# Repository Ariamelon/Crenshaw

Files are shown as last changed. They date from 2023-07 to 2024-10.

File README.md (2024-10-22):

# Crenshaw
1.5" SSD1351 RGB OLED [VIK](https://github.com/sadekbaroudi/vik) module.

## Disclaimer
This board is licensed under CERN-OHL-S-2.0.

## VIK module certification card

| Category | Classification | Response |
| --- | --- | --- |
| FPC connector | Required | :heavy_check_mark: |
| Breakout pins | Recommended | :x: |
| Uses: SPI | Optional | :heavy_check_mark: |
| SPI used for SPI only | Strongly recommended | :heavy_check_mark: |
| Uses: I2C | Optional | :x: |
| I2C used for I2C only | Strongly Recommended | N/A |
| I2C pull ups | Required | N/A |
| Uses: RGB | Optional | :x: |
| Uses: Extra GPIO 1 | Optional | :heavy_check_mark: |
| Uses: Extra GPIO 2 | Optional | :heavy_check_mark: |
| Standard PCB Size/Mount | Strongly Recommended | :x: |

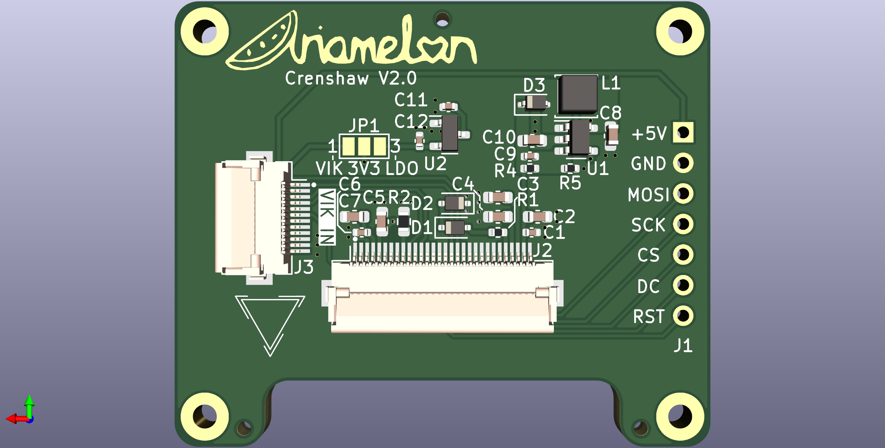
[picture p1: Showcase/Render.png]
Render


## Changelog
 * 22/10/2024: License updated to CERN-OHL-S-2.0.
* 04/08/2023: Changed VIK and OLED FFC to FH12. Stitched ground planes together. Fixed VIK footprint. Moved production files to easier to access location.
* 28/07/2023: Added pin labels. Added VIK size row to certification card.
* 27/07/2023: Added voltage regulator, SSD1351 supporting circuitry and [VIK](https://github.com/sadekbaroudi/vik) connector. Added license. Added metadata to schematic and board files. Added VIK module certification card.
* 26/07/2023: Updated to V2.0.
* 11/11/2020: Updated to V1.2. Slightly increased size. Moved ribbon cable connector away from center of board as it was causing issues where it was. Spread components apart to allow for easier soldering.
* 30/09/2020: Updated to V1.1. Fixed orientation of I2C headers, increased silkscreen text size, moved ribbon cable connector further towards center of board.
* 29/09/2020: D1 SOD323 switched to SOD123.
* 27/09/2020: Initial commit.

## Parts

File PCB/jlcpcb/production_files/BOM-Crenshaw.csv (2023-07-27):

Comment | Designator | Footprint | LCSC
22p | C9 | C_0402_1005Metric | C1555
1u | C3,C4,C5,C7 | C_0603_1608Metric | C15849
1N5819WS | D3 | D_SOD-323 | C191023
4u7 | C10,C8 | C_0603_1608Metric | C19666
10u | L1 | L_Sunlord_SWPA3012S | C206385
1N4148 | D1,D2 | D_SOD-323 | C2128
560k | R2 | R_0603_1608Metric | C23203
51 | R1 | R_0402_1005Metric | C25125
100k | R5 | R_0402_1005Metric | C25741
1M | R4 | R_0402_1005Metric | C26083
100n | C1,C6 | C_0402_1005Metric | C307331
SSD1351 | J2 | HRS_FH34SRJ-30S-0.5SH(50) | C324727
VIK Module | J3 | vik-module-connector-horizontal | C424659
1u | C11,C12 | C_0402_1005Metric | C52923
XC6206P332MR | U2 | SOT-23 | C5446
TPS61040DBV | U1 | SOT-23-5 | C7722
10u | C2 | C_0603_1608Metric | C96446
OLED_Breakout | J1 | OLED_1.5_SSD1351_128x128

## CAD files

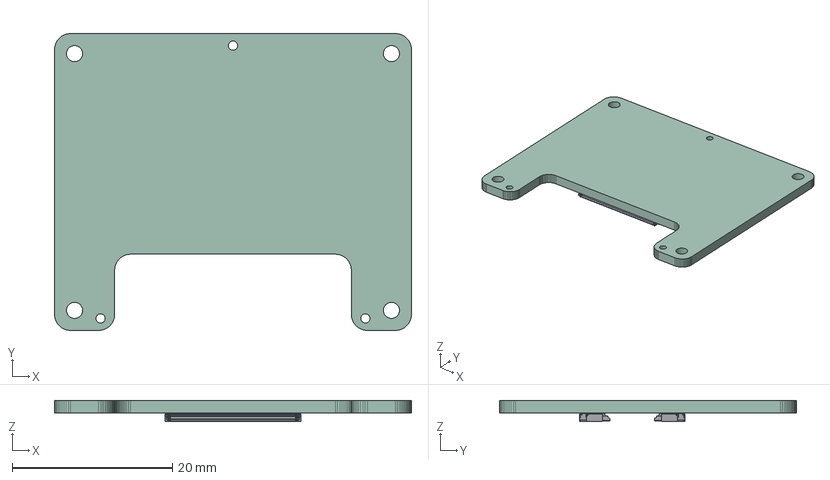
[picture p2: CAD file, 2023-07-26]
Showcase/Crenshaw.step
44.5 x 37.0 x 2.65 mm
Crenshaw PCB

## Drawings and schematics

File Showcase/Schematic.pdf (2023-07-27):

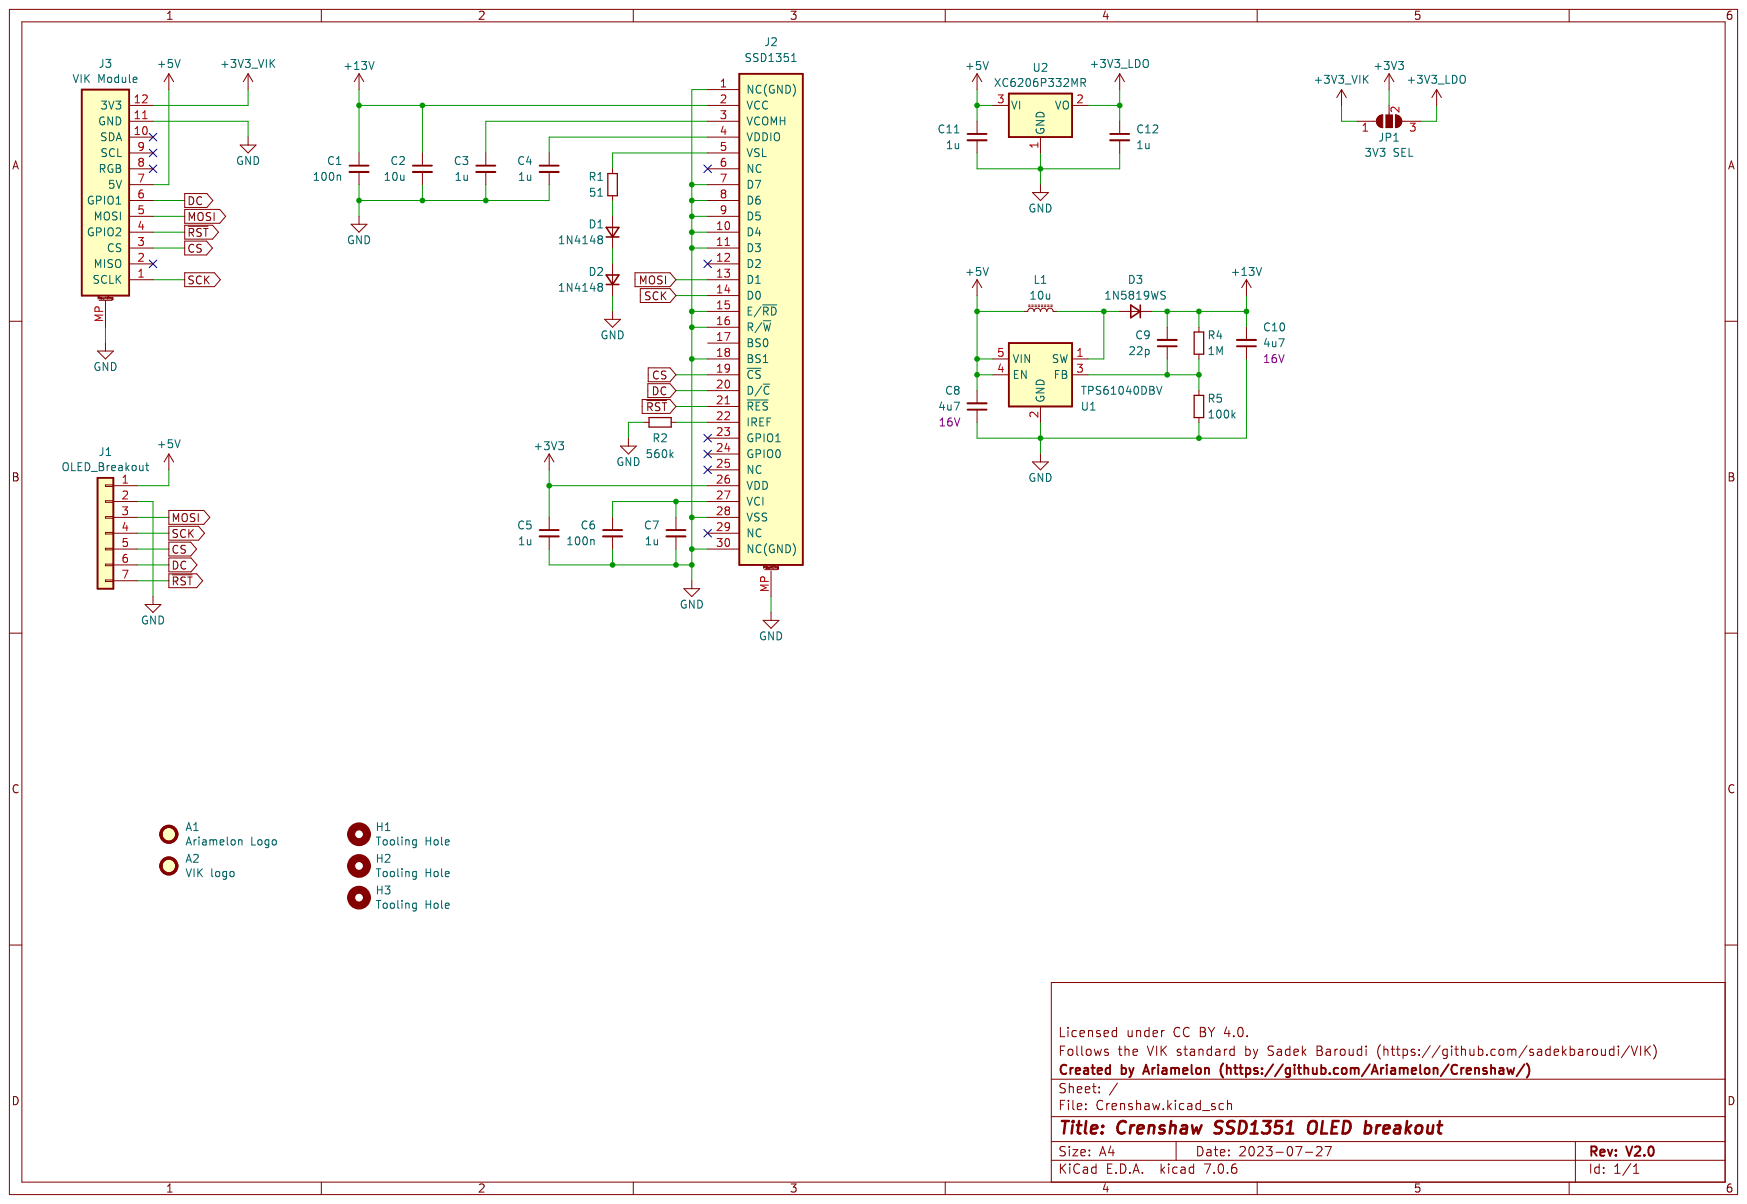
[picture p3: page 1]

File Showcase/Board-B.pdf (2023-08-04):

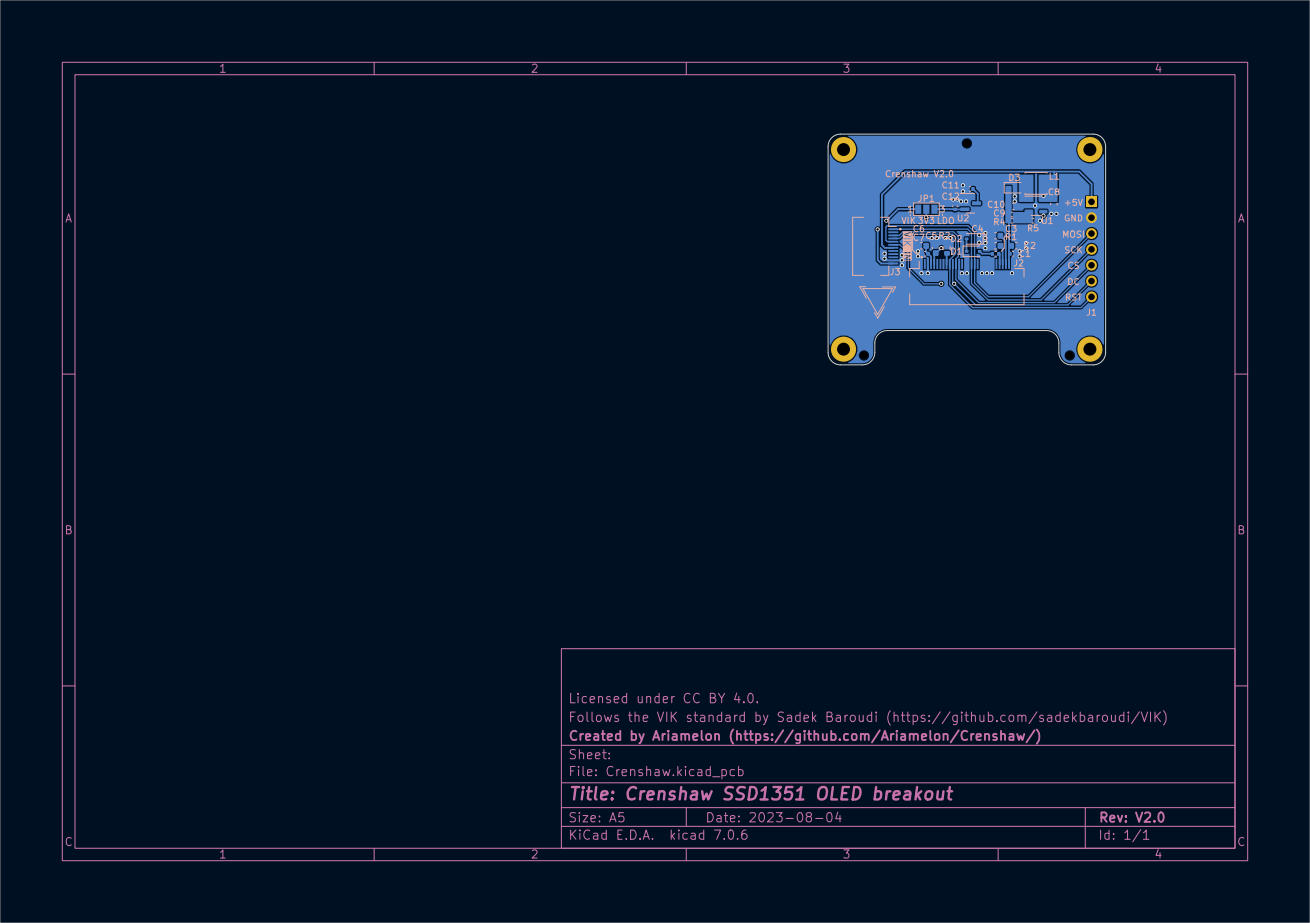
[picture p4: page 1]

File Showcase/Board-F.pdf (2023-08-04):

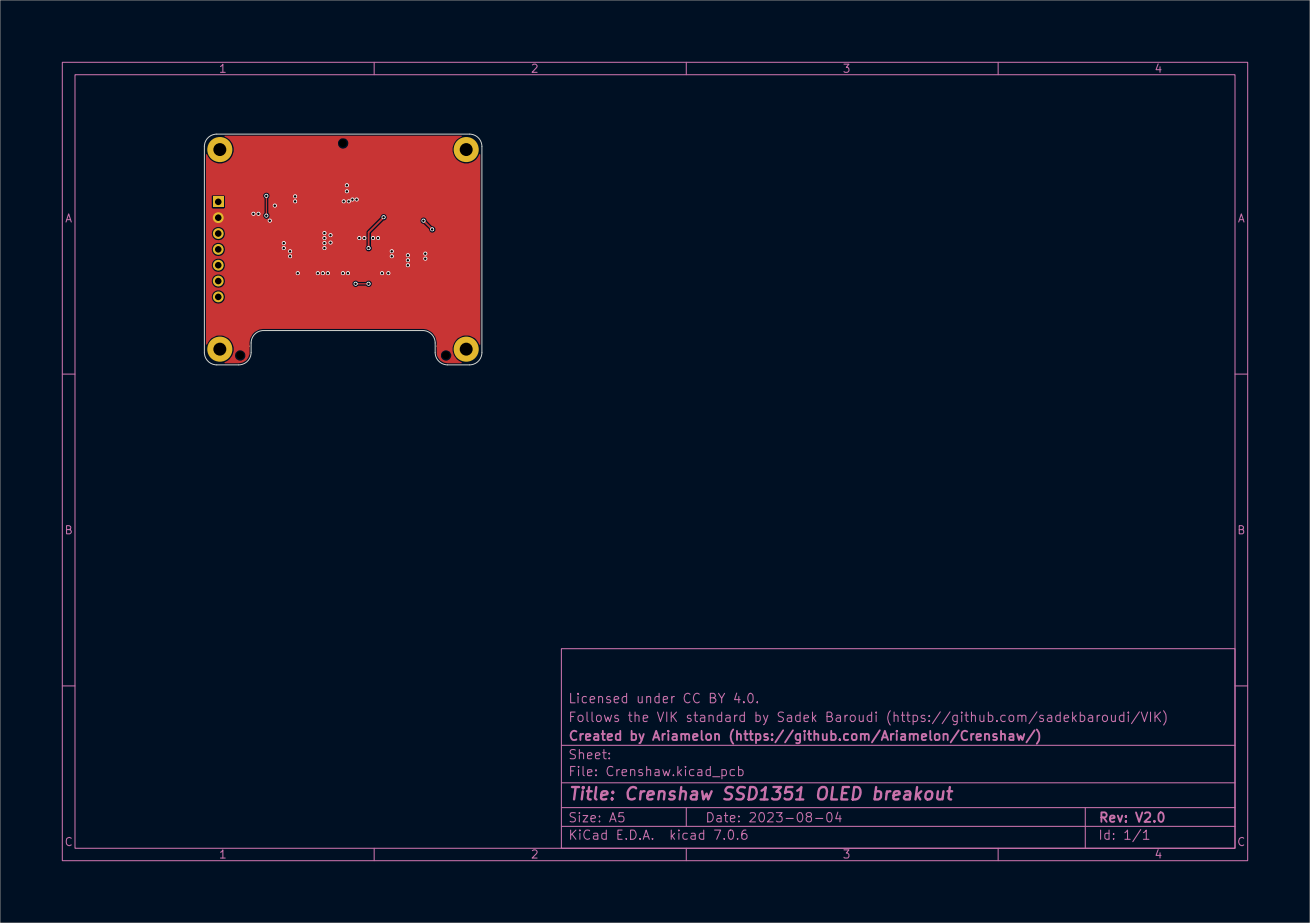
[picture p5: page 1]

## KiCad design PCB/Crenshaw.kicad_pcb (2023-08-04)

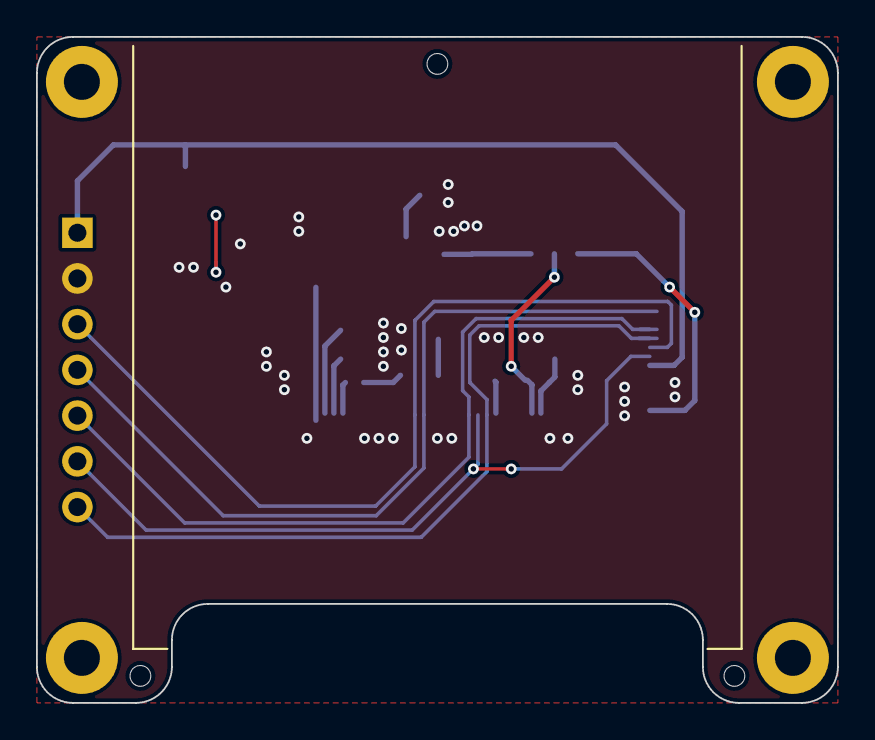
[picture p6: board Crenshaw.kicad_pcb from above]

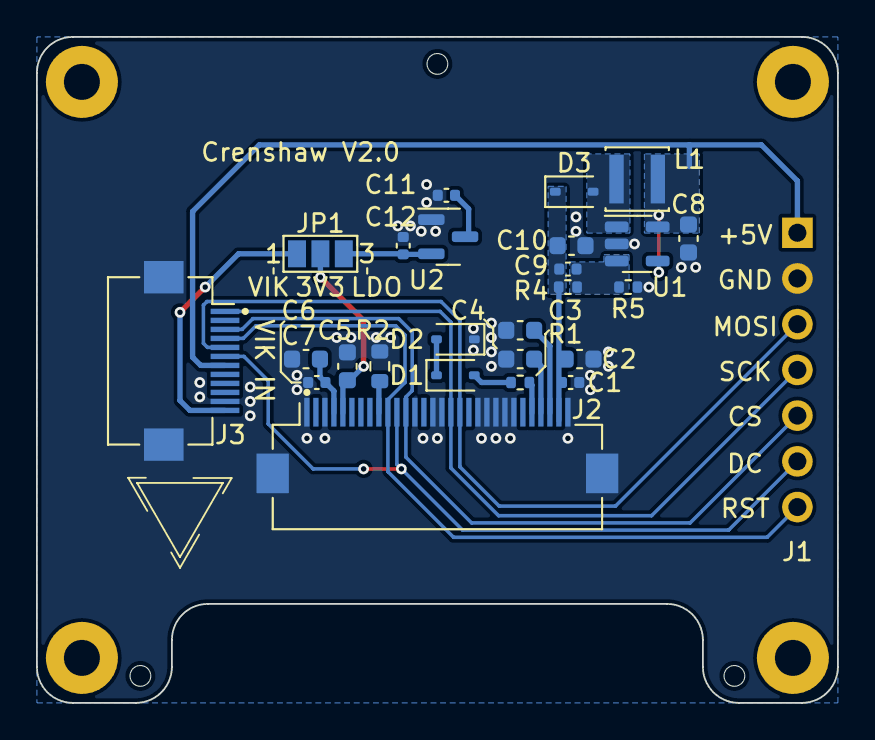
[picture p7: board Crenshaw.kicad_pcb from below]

Board: 2 copper layers, 44.5 x 37.0 mm, 31 parts (27 on the bottom side), 20 nets.

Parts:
A1: Ariamelon Logo; Ariamelon_Logo_x2_Mask
A2: VIK logo; vik-logo-small
C1, C6: 100n; C_0402_1005Metric
C2: 10u; C_0603_1608Metric
C3, C4, C5, C7: 1u; C_0603_1608Metric
C8, C10: 4u7; C_0603_1608Metric
C9: 22p; C_0402_1005Metric
C11, C12: 1u; C_0402_1005Metric
D1, D2: 1N4148; D_SOD-323
D3: 1N5819WS; D_SOD-323
H1, H2, H3: Tooling Hole; JLC Tooling Hole
J1: OLED_Breakout; OLED_1.5_SSD1351_128x128
J2: SSD1351; Hirose_FH12-30S-0.5SH_1x30-1MP_P0.50mm_Horizontal
J3: VIK Module; vik-module-connector-horizontal
JP1: 3V3 SEL; SolderJumper-3_P1.3mm_Open_Pad1.0x1.5mm_NumberLabels
L1: 10u; L_Sunlord_SWPA3012S
R1: 51; R_0402_1005Metric
R2: 560k; R_0603_1608Metric
R4: 1M; R_0402_1005Metric
R5: 100k; R_0402_1005Metric
U1: TPS61040DBV; SOT-23-5
U2: XC6206P332MR; SOT-23

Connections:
+3V3: C5.1, J2.5 (VDD), JP1.2 (C)
+3V3_LDO: C12.1, JP1.3 (B), U2.2 (VO)
+3V3_VIK: J3.12 (3V3), JP1.1 (A)
+5V: C8.2, C11.1, J1.1, J3.7 (5V), L1.2, U1.4 (EN), U1.5 (VIN), U2.3 (VI)
+13V: C1.1, C2.1, C9.2, C10.2, D3.1 (K), J2.29 (VCC), R4.2
CS: J1.5, J2.12 (~CS), J3.3 (CS)
DC: J1.6, J2.11 (D/~C), J3.6 (GPIO1)
GND: C1.2, C2.2, C3.2, C4.2, C5.2, C6.2, C7.2, C8.1, C10.1, C11.2, C12.2, D2.1 (K), J1.2, J2.1 (NC(GND)), J2.3 (VSS), J2.13 (BS1), J2.15 (R/~W), J2.16 (E/~RD), J2.20 (D3), J2.21 (D4), J2.22 (D5), J2.23 (D6), J2.24 (D7), J2.30 (NC(GND)), J2.MP, J3.11 (GND), J3.MP, R2.2, R5.2, U1.2 (GND), U2.1 (GND)
MOSI: J1.3, J2.18 (D1), J3.5 (MOSI)
unnamed: D1.2 (A), R1.1
unnamed: D1.1 (K), D2.2 (A)
unnamed: D3.2 (A), L1.1, U1.1 (SW)
unnamed: J2.9 (IREF), R2.1
unnamed: C6.1, C7.1, J2.4 (VCI)
unnamed: C3.1, J2.28 (VCOMH)
unnamed: C4.1, J2.27 (VDDIO)
unnamed: J2.26 (VSL), R1.2
unnamed: C9.1, R4.1, R5.1, U1.3 (FB)
SCK: J1.4, J2.17 (D0), J3.1 (SCLK)
~RST: J1.7, J2.10 (~RES), J3.4 (GPIO2)

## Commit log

2020-09-28 Added Gerber files
    [Crenshaw-B_Cu.gbr, Crenshaw-B_Mask.gbr, Crenshaw-B_Paste.gbr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]
2020-09-28 Added BOM
    [Crenshaw-BOM.csv, Crenshaw-BOM.xlsx]
2020-09-29 SOD323 schottky switched to SOD123
    Bigger means less heat issues
    [Crenshaw-BOM.csv, Crenshaw-BOM.xlsx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]
2020-09-30 Updated to V1.1 - fixed several major errors
    Fixed issue with orientation of I2C headers, increased size of silkscreen text, and moved ribbon cable connector lower down the board.
    [Crenshaw-B_Cu.gbr, Crenshaw-B_Mask.gbr, Crenshaw-B_Paste.gbr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]
2020-10-01 Added renders and updated readme
    [Crenshaw.kicad_pcb]
2020-10-02 Updated BOM
    [Crenshaw-BOM.csv, Crenshaw-BOM.xlsx]
2020-10-24 Better render
    [Crenshaw.kicad_pcb]
2020-11-10 Updated to V1.2
    [Crenshaw-B_Cu.gbr, Crenshaw-B_Mask.gbr, Crenshaw-B_Paste.gbr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]
2023-07-26 V2.0 released
    Now an adapter board for the SSD1351 that is just a 1 to 1 FFC cable adapter.
    [BOM-Crenshaw.csv, Crenshaw-BOM.csv, Crenshaw-BOM.xlsx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]
2023-07-27 27/03/2023 update
    Added voltage regulator, SSD1351 supporting circuitry and [VIK](https://github.com/sadekbaroudi/vik) connector. Added license. Added metadata to schematic and board files. Added VIK module certificat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
    [BOM-Crenshaw.csv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]
2023-07-28 28/07/2023 update
    Added pin labels. Added VIK size row to certification card.
    [CPL-Crenshaw.csv, Crenshaw-CuBottom.gbr, Crenshaw-CuTop.gbr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]
2023-08-04 04/08/2023 update
    Changed VIK and OLED FFC to FH12. Stitched ground planes together. Fixed VIK footprint. Moved production files to easier to access location.
    [BOM-Crenshaw.csv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]

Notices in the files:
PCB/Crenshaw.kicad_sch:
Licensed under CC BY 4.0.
